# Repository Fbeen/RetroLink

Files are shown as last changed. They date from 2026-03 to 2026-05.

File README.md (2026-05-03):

# RetroLink

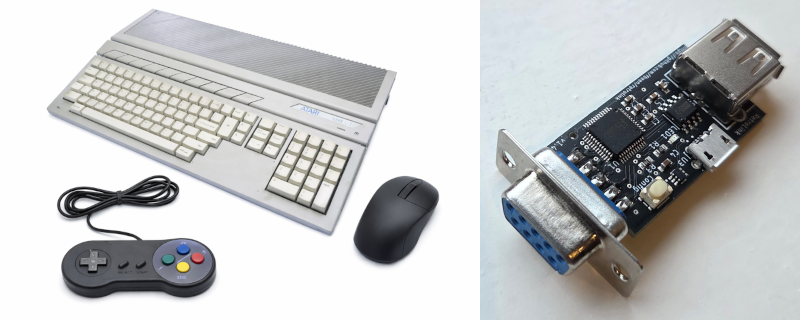
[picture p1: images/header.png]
Retro computer


RetroLink is a small **USB input adapter for retro computers**.

It allows modern **USB mice and USB joysticks** to be used on classic systems such as:

- Atari ST
- Commodore Amiga
- Commodore 64

---

## Table of Contents

- [Features](#features)
- [Button Control & LED Feedback](#button-control--led-feedback)
- [Why This Project Exists](#why-this-project-exists)
- [How RetroLink Works](#how-retrolink-works)
  - [Microcontroller](#microcontroller-ch559l)
  - [USB Host Operation](#usb-host-operation)
  - [Mouse Emulation](#mouse-emulation)
  - [Joystick Mapping](#joystick-mapping)
  - [Open Collector Outputs](#open-collector-outputs)
  - [Serial Interface](#serial-configuration-interface)
- [Hardware](#hardware)
- [Connecting RetroLink](#connecting-retrolink)
- [Configuration Console](#opening-the-configuration-console)
- [Menu Options](#main-menu)
- [Firmware](#firmware)
- [Disclaimer](#disclaimer)

---

## Features

- USB mouse support
- USB joystick support, must be a HID joystick.
- Works with **Atari 8 bit**,  **Atari ST**, **Amiga**, and **C64**
- Configurable **mouse speed**
- Switch between **ST mouse** and **Amiga mouse**
- **Swap** left & right **mouse buttons**
- Configurable **autofire frequency**
- **Joystick learning wizard**
- Configuration stored in flash memory
- Terminal-based configuration (optional)
- Configurable with onboard button & LED

---

# Button Control & LED Feedback

## Button Overview

The RetroLink uses **one button**:

- **Short press**  Show menu on UART  
- **Long press**  Select function via LED flashes  

---

## Short Press

**< 1 second**

- Prints the **Main Menu**
- Useful when opening a serial terminal  

---

## Long Press (Selection)

| Flashes | Function |
|---|---|
| 1 | Controller Learning |
| 2 | Swap Mouse Mode |
| 3 | Swap Mouse Buttons |
| 4 | Increase Mouse Speed |
| 5 | Increase Autofire Speed |

Release at desired flash count

---

## Controller Learning (1 flash)

Press a key on your controller in the order below to configure it:

1. UP  
2. DOWN  
3. LEFT  
4. RIGHT  
5. FIRE  
6. AUTOFIRE  

### Feedback

- Each step **2 short flashes**
- Final step LED ON for **2 seconds**
- Config is saved automatically

### To abort the learning wizzard:

- Press **PCB button**
- Press **ESC** in terminal

---

## Mouse Mode (2 flashes)

- 1 flash Atari ST  
- 2 flashes Amiga  

---

## Mouse Buttons (3 flashes)

- 1 flash Normal  
- 2 flashes Swapped  

---

## Mouse Speed (4 flashes)

Cycles from 1 to 5 

| Flashes | Speed |
|---|---|
| 1 | Very Slow |
| 2 | Slow |
| 3 | Normal |
| 4 | Fast |
| 5 | Turbo |

---

## Autofire Speed (5 flashes)

| Flashes | Frequency |
|---|---|
| 1 | 8 Hz |
| 2 | 9 Hz |
| 3 | 10 Hz |
| 4 | 11 Hz |
| 5 | 12 Hz |

---

## Notes

- Settings are stored in flash
- Persist after reboot
- LED is primary UI without UART

---

# Why This Project Exists

Classic hardware is aging:

- cables break  
- hardware wears out  
- ergonomics are outdated  

RetroLink solves this by allowing **modern USB devices** to be used.

---

# How RetroLink Works

RetroLink translates USB input into **DB9 signals**.

Internally:

- USB HID reports are read
- Converted to:
  - quadrature signals (mouse)
  - digital lines (joystick)
  - autofire pulses

---

## Microcontroller: CH559L

I chose the CH559 because it operates directly on the 5 volts from the retro computer and therefore does not require a power regulator. Furthermore, the CH559 microcontroller has a built-in USB transceiver and USB controller. The DB9 interfaces are electrically very simple, but they rely on a specific signaling method: open-collector (or open-drain) logic.

Key features for the CH559:

- 8051-based MCU
- USB Host + Device
- 5V operation and low current 3.3v output
- Built-in flash storage

### RAM Limitation

The disadvantage of the CH559 is the small RAM size. That's why strings are stored in flash using `__code`, for example:

    static const char __code text[] = "Example";

---

## USB Host Operation

Supports HID devices:

- mouse
- joystick
- gamepads

---

## Mouse Emulation

Uses quadrature encoding:

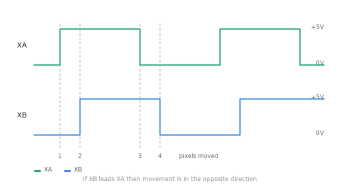
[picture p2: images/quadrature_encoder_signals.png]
quadrature


---

## Joystick Mapping

Learning wizard detects:

- changed bytes
- thresholds
- control mapping

---

## Open Collector Outputs

Uses open-drain signals:

- only pulls LOW
- host provides pull-up

---

## Serial Configuration Interface

The RX and TX UART0 lines are connected to the CH340N UART-to-USB controller. This ensures that a micro USB cable can be used for the configuration.

---

# Hardware

See the [hardware section](/hardware/readme.md).

---

# Connecting RetroLink

1. Plug into DB9 mouse or joystick port on your Atari 8 bit / ST / Amiga /C64
2. Connect HID mouse/controller to the USB-A port
3. *Optional: connect micro USB cable to your PC to use the console*
4.  For joystick emulation run the **learning wizzard** once.

---

# Opening the Configuration Console

Connect a USB cable from your pc to the micro USB port on the pcb. Any serial console could be used like:

- Arduino's serial monitor
- Visual Studio Code's serial monitor
- PuTTY
- TeraTerm
- minicom

Settings:

```
2000000 baud
8 data bits
no parity
1 stop bit
```
---

## Main Menu

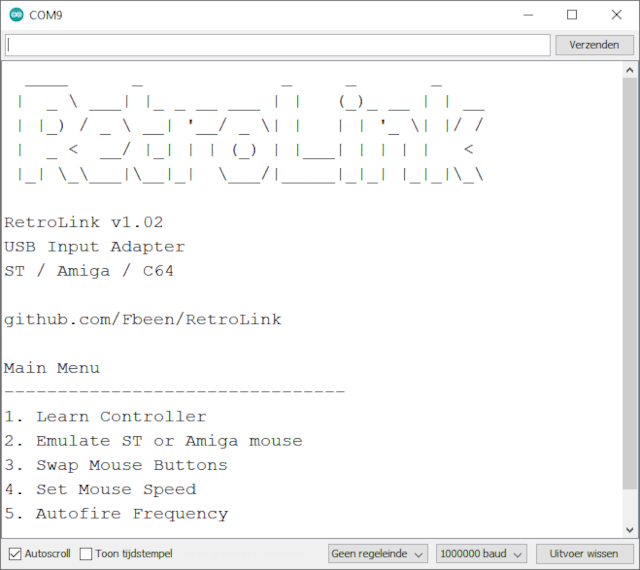
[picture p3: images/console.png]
Main menu


---

# Firmware

See the [firmware section](/firmware.md).

---

# Repository

https://github.com/Fbeen/RetroLink

---

# Disclaimer

Provided as-is. Use at your own risk.

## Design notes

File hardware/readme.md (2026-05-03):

# Hardware

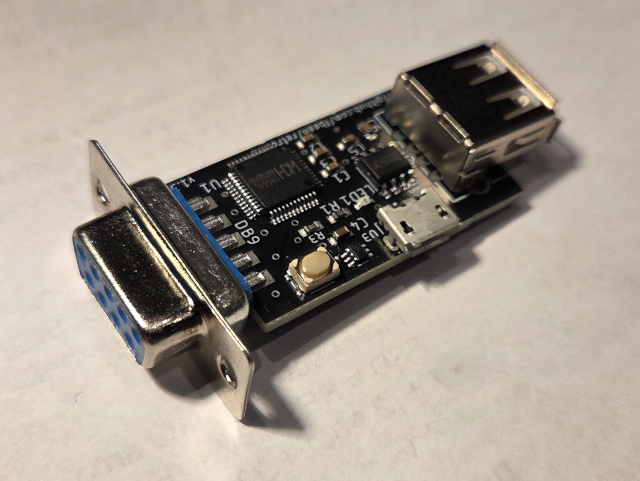
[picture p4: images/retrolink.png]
RetroLink


The RetroLink hardware was designed in **Autodesk EAGLE**.

If you want to modify the design yourself, you can download Autodesk EAGLE for free through the **Fusion 360 Personal Use License**. This license is intended for hobbyists and non-commercial projects.

Useful links:

https://www.autodesk.com/products/fusion-360/personal  
https://www.autodesk.com/products/eagle/overview  

The free version has a few limitations, but for small hobby projects like this it works perfectly fine:

- Maximum **2 schematic sheets**
- Maximum **2 signal layers**
- Maximum **100 cm² PCB area**

---

# Ordering the PCB at JLCPCB

You can simply order it **almost fully assembled** from JLCPCB.

To make this easy, the repository already contains the required manufacturing files.

You will find them here: `hardware/jlcpcb.com/`

Inside that folder you will find:

- `CAMOutput.zip` – the Gerber files (PCB manufacturing files)
- `bom.xls` – Bill of Materials
- `cpl.xls` – Component placement file

---

## Step-by-step ordering

1. Go to https://jlcpcb.com

2. Log in or create an account.

3. Press **Order Now**

4. Upload the file: `CAMOutput.zip`

5. Choose your preferred **PCB color**

6. Enable **PCB Assembly**

7. Select the quantity  
(usually **2 or 5 boards** is the cheapest option)

8. Press **Next**

9. Press **Next** again

10. Upload the assembly files

- BOM file → `bom.xls`
- CPL file → `cpl.xls`

11. Press **Process BOM & CPL**

12. **Important:** carefully check the detected parts.

13. Press **Next**

14. Check the orientation of the following components:

- **U1** → dot at **bottom-left**
- **U2** → dot at **top-right**
- **U3** → dot at **bottom-right**
- **LED** → **left = negative**, **right = positive**

15. Press **Save to cart**

16. Place your order and complete payment.

17. Now comes the hardest part: **waiting for the package to arrive.**

---

# Adding the DB9 and USB-A connectors

The **DB9** and **USB-A** connectors are **not assembled by JLCPCB**, so you will need to solder them yourself.

Luckily this is very easy and only takes a few minutes.

You will need:

- **DB9 Connector – PCB Mount – Serial – 9 Pin – 2 Rows**
- **USB-A Connector – PCB Mount**

Example connectors:

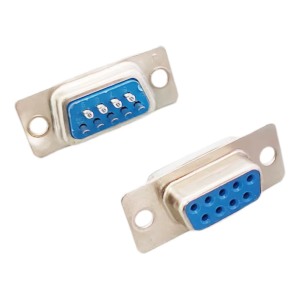
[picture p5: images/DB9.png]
DB9 Connector PCB Mount Serial 9 Pin 2 Rows


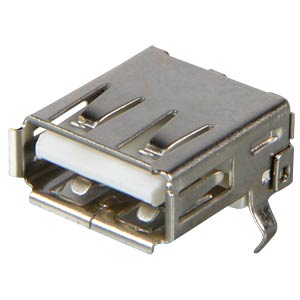
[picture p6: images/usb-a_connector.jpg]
USB-A connector pcb mount


---

# Compiling and flashing the firmware (Windows)

The **CH559L microcontroller** can be programmed directly through USB.

For this you will need a **USB-A to USB-A cable**.

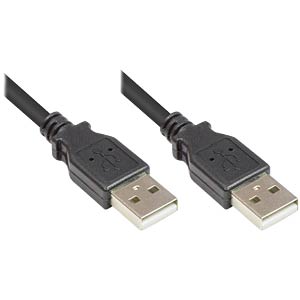
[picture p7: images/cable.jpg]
USB-A to USB-A cable


---

## Compiling and flashing instructions

1. Clone the complete repository

https://github.com/Fbeen/RetroLink

or use:

```
git clone https://github.com/Fbeen/RetroLink
```

2. Open a **Command Prompt** in Windows.

3. Change to the repository directory

```
cd RetroLink
```

4. Connect the PCB to your computer using the **USB-A to USB-A cable**  
while **holding the button on the PCB**.

5. If everything goes well you should hear the familiar  
**"new USB device detected"** sound from Windows.

6. Run the build script:

```
cd scripts
compile
```

The firmware will now be compiled and flashed to the **CH559L**.

---

# Repository

The complete project can be found here:

https://github.com/Fbeen/RetroLink

Feel free to explore the project, modify the hardware or firmware, and build your own RetroLink adapter.

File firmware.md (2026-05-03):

# RetroLink Firmware (CH559)

Firmware for the RetroLink adapter: a USB-to-retro controller interface (Atari ST / Amiga / C64).

This firmware runs on the **CH559 (8051 + USB host)** and translates USB HID input (mouse / joystick / gamepad) into classic digital and quadrature signals.

---

## Compiling and flashing instructions

See the [hardware section](/hardware/readme.md#compiling-and-flashing-the-firmware-windows).

---

## About the Firmware Language

This firmware is written in a specialized dialect of **C targeting the 8051 architecture**, specifically for the **WCH CH559 microcontroller**.

Although it looks like standard C, there are several important differences compared to desktop or ARM-based embedded development:

- Uses **8051-specific memory qualifiers** such as:
  - `__code` (flash memory)
  - `__xdata`, `__idata`, etc. (different RAM regions)
- Strong awareness of **very limited RAM**
- Heavy reliance on **interrupt-driven design**
- Direct manipulation of **special function registers (SFRs)**
- Tight coupling to hardware timing (especially for quadrature signals)

Because of this, the code is closer to **"embedded C for 8-bit MCUs"** than modern C used on platforms like ARM Cortex (e.g. STM32 or RP2040).

### Why this matters

If you plan to modify or extend this firmware:

- Be mindful of **memory placement** (RAM vs flash)
- Avoid large stack usage or dynamic allocation
- Keep interrupt routines **fast and deterministic**
- Understand that some constructs are compiler- or architecture-specific

In short: this is **low-level, hardware-near C**, optimized for a small 8-bit microcontroller rather than a general-purpose system.

---

# Purpose of this README

This document is intended to:

- Help new developers quickly understand the project
- Make maintenance and extensions easier
- Provide insight into architecture, timing, and hardware interaction

---

# Project Structure

The firmware is modular and split by functionality:

    main.c              entry point + main loop + timers
    USBHost.c           USB host stack + HID handling
    hid_mouse.c         USB mouse report parsing
    hid_joystick.c      USB joystick/gamepad parsing

    retro_mouse.c       quadrature signal generation (Atari/Amiga)
    retro_joystick.c    digital joystick output

    hardware.c          GPIO setup and hardware initialization
    led.c               LED timing and animations
    console.c           UART debug / configuration interface

    config.c            persistent configuration + mappings
    util.c              helper functions

---

# Firmware Architecture

## 1. Data Flow (High-Level)

### Mouse pipeline:

    USB HID report
     hid_mouse_parse()
     movement buffer (mx/my)
     timer interrupt
     rm_nextStep()
     quadrature output (PORT2)

### Joystick pipeline:

    USB HID report
     hid_joystick_parse()
     mapping via config
     direct GPIO output (ACTIVE LOW)

---

## 2. Main Loop (main.c)

`main.c` is responsible for:

- Initialization:
  - Clock setup
  - USB host
  - GPIO
  - Timers
- Polling:
  - USB devices (USBHost_*)
- Mode switching:
  - Mouse vs joystick

---

# GPIO & Hardware

## GPIO Definition

GPIO is centrally managed in:

    hardware.c

This file defines:

- Direction (input/output)
- Open-drain / push-pull modes
- Default signal levels

### Important:

- **All joystick signals are ACTIVE LOW**
- Idle = HIGH
- Active = LOW

---

## Output Mapping

Typically using `PORT2`:

| Function | Signal |
|---|---|
| UP | GPIO |
| DOWN | GPIO |
| LEFT | GPIO |
| RIGHT | GPIO |
| FIRE | GPIO |

Mouse signals:

- Quadrature signals (X1/X2, Y1/Y2)
- Layout differs between Atari ST and Amiga

---

## Open Drain Behavior

The firmware uses:

- Open-drain / open-collector style outputs
- Safe for retro hardware
- Mimics original joystick electronics

---

# Timers

## Timer0 (Main Timing Engine)

Used for:

- Mouse quadrature timing
- Autofire
- LED timing
- Button handling

Configured in `main.c`:

    #define mTimer0ClkFsys()

---

## Timing Functions

### 1. Mouse Stepping

Executed in ISR:

    rm_nextStep()

- Processes mx/my buffers
- Generates correct quadrature phase sequence

---

### 2. Autofire

Key variables:

    autofire_counter
    autofire_state

- ~2400 Hz interrupt base
- ~10 Hz output signal

---

### 3. Button Timing

    BTN_STEP   = 10   ~1 second
    BTN_T_BOOT = 100  ~10 seconds

Used for:

- Short press detection
- Long press detection
- Menu selection

---

# USB HID Processing

## USB Stack

File:

    USBHost.c

Responsibilities:

- Device enumeration
- HID interface selection
- Polling

---

## Device Detection

- Protocol 2 Mouse
- Otherwise Joystick/Gamepad

---

## Parsing

### Mouse:

    hid_mouse.c

- X/Y movement
- Buttons

### Joystick:

    hid_joystick.c

- Axis direction
- Buttons fire/autofire

---

# Retro Output

## Mouse (retro_mouse.c)

- Maintains mx/my buffers
- Generates quadrature signals
- Supports:
  - Atari ST
  - Amiga

---

## Joystick (retro_joystick.c)

- Direct GPIO mapping
- Active LOW output
- Configurable mapping

---

# Configuration

File:

    config.c

Contains:

- Controller mappings
- Mouse speed
- Autofire settings
- Button swap
- Mode (ST/Amiga)

Storage:

- Flash memory
- Version/magic validation

---

# LED & UI

File:

    led.c

Handles:

- Status feedback
- Menu navigation

---

## Button + LED UI

| Action | Result |
|---|---|
| Short press  | Show menu (UART)  |
| Long press | Select option |
| LED flashes  | Menu index |

---

# Console (UART)

File:

    console.c

Features:

- Debug output
- Configuration interface
- Menu system

---

# Utilities

File:

    util.c

Contains:

- Helper functions
- Parsing utilities
- General shared logic

---

# Important Notes

## 1. Limited RAM

- CH559 has very limited RAM
- Store constant data in `__code` (flash)

---

## 2. Timing is Critical

- Mouse quadrature must be precise
- ISR must remain lightweight

---

## 3. USB Polling

- Must run frequently
- Avoid blocking code in main loop

---

## 4. Open Drain Outputs

- Never force push-pull on retro lines
- Prevents hardware damage

---

# How to Extend

## Adding New Features

Typical workflow:

1. Extend parsing in:
   - hid_*
2. Add mapping in:
   - config.c
3. Adjust output in:
   - retro_*
4. Extend UI:
   - console.c
   - led.c

---

## Adding New Hardware

- Update GPIO config in `hardware.c`
- Keep mappings consistent

---

# Summary

This firmware is built around:

- **USB HID input**
- **Timer-driven output**
- **Strict timing**
- **Modular design**

Core principles:

- Keep ISR minimal
- Use buffers for decoupling
- Drive hardware safely

---

# Final Notes

If you want to understand or extend this project:

1. Start with `main.c` (overall flow)
2. Then study `USBHost.c` (input layer)
3. Finally inspect `retro_*` (output layer)

This gives you a complete understanding of the system.

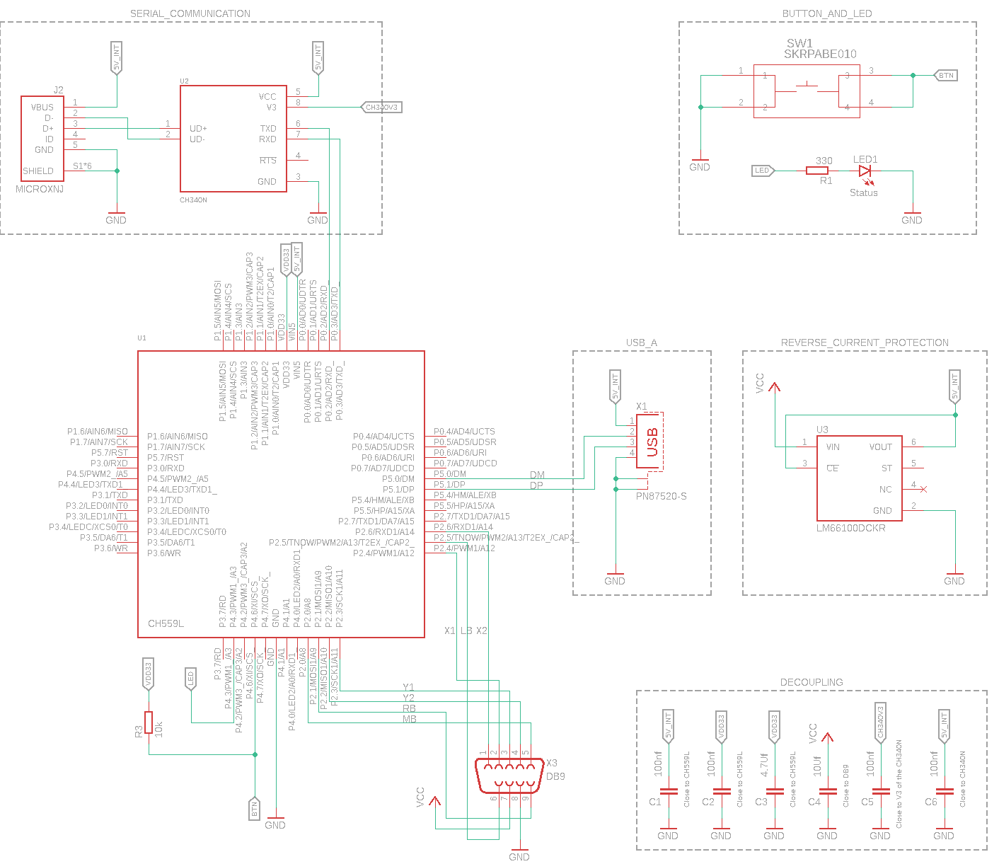
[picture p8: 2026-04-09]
hardware/schema.png

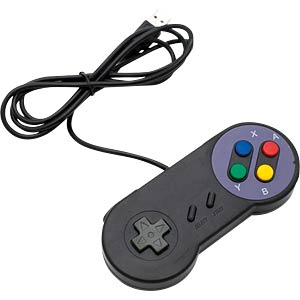
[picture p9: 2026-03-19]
images/gamepad.jpg

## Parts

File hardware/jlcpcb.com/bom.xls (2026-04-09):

Comment | Designator | Footprint | JLCPCB Part #
100nf | C1 | C0603 | C14663
100nf | C2 | C0603 | C14663
4.7Uf | C3 | C0603 | C107368
10Uf | C4 | C0603 | C49326609
100nf | C5 | C0603 | C14663
100nf | C6 | C0603 | C14663
USB-MICRO XNJ JB | J1 | Custom | C7507410
Status | LED1 | SML0603 | C2287
330 | R1 | R0603 | C23138
10k | R3 | R0603 | C25804
SKRPABE010 | SW1 | SW4_SKRPABE010_ALPS | C115360
CH559L | U1 | TQFP48_7X7 | C150548
CH340N | U2 | SOIC127P600X160-8N | C2977777
LM66100DCKR | U3 | SOT65P210X110-6N | C2869734

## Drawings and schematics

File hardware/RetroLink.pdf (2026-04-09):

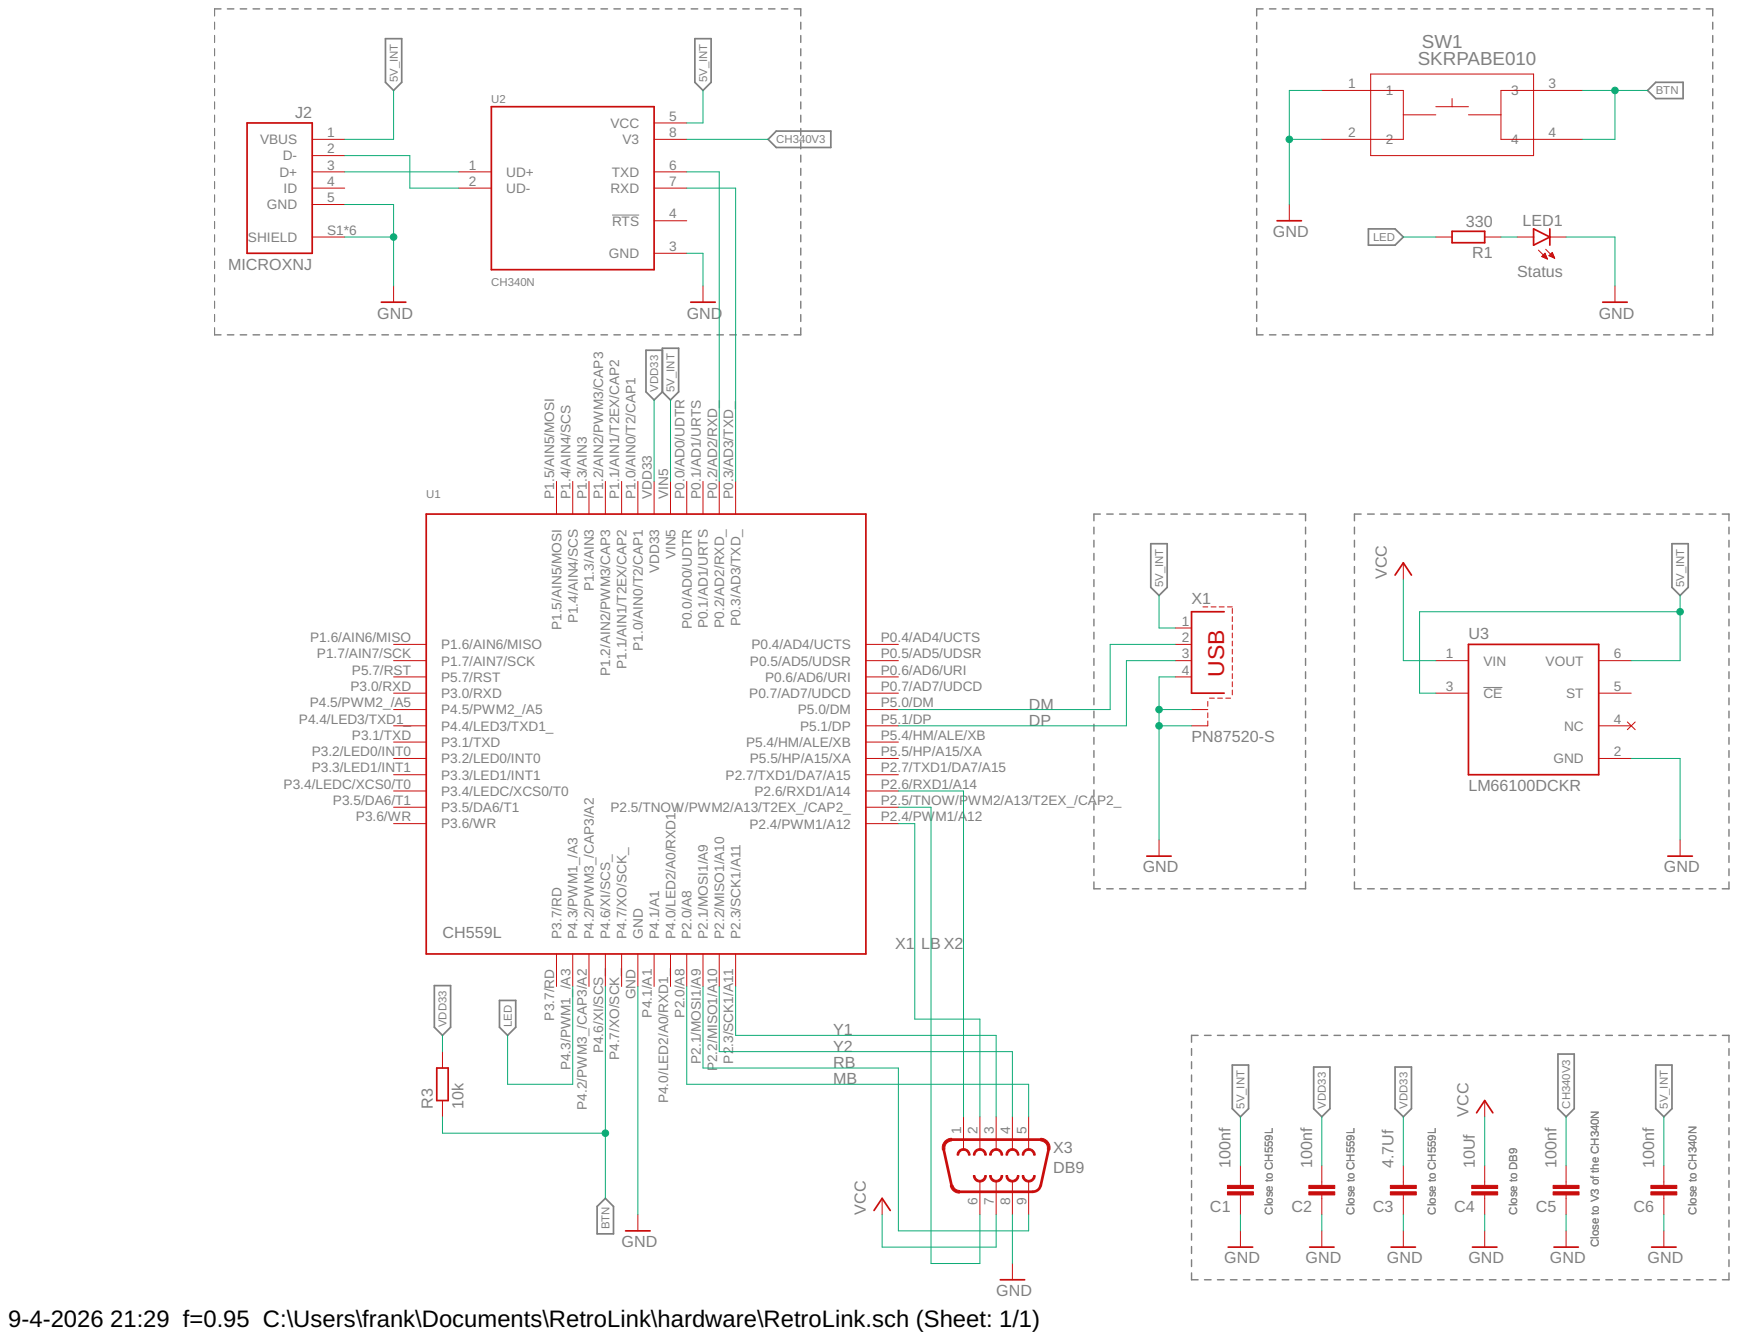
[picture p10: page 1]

3 GND | 6 RXD

P4.1/A1 P4.1/A1 P4.0/LED2/A0/RXD1_ P4.0/LED2/A0/RXD1_ P2.0/A8 P2.0/A8 P2.1/MOSI1/A9 P2.1/MOSI1/A9 P2.2/MISO1/A10 P2.2/MISO1/A10 P2.3/SCK1/A11 P2.3/SCK1/A11 P2.4/PWM1/A12 P2.4/PWM1/A12 P2.5/TNOW/PWM2/A13/T2EX_/CAP2_ P2.5/TNOW/PWM2/A13/T2EX_/CAP2_ P2.6/RXD1/A14 P2.6/RXD1/A14 P2.7/TXD1/DA7/A15 P2.7/TXD1/DA7/A15 P5.5/HP/A15/XA

P4.3/PWM1_/A3 P4.3/PWM1_/A3 P4.2/PWM3_/CAP3/A2 P4.2/PWM3_/CAP3/A2 P4.6/XI/SCS_ P4.6/XI/SCS_ P4.7/XO/SCK_ P4.7/XO/SCK_ GND GND

Close to V3 of the CH340N

9-4-2026 21:29 f=0.95 C:\Users\frank\Documents\RetroLink\hardware\RetroLink.sch (Sheet: 1/1)

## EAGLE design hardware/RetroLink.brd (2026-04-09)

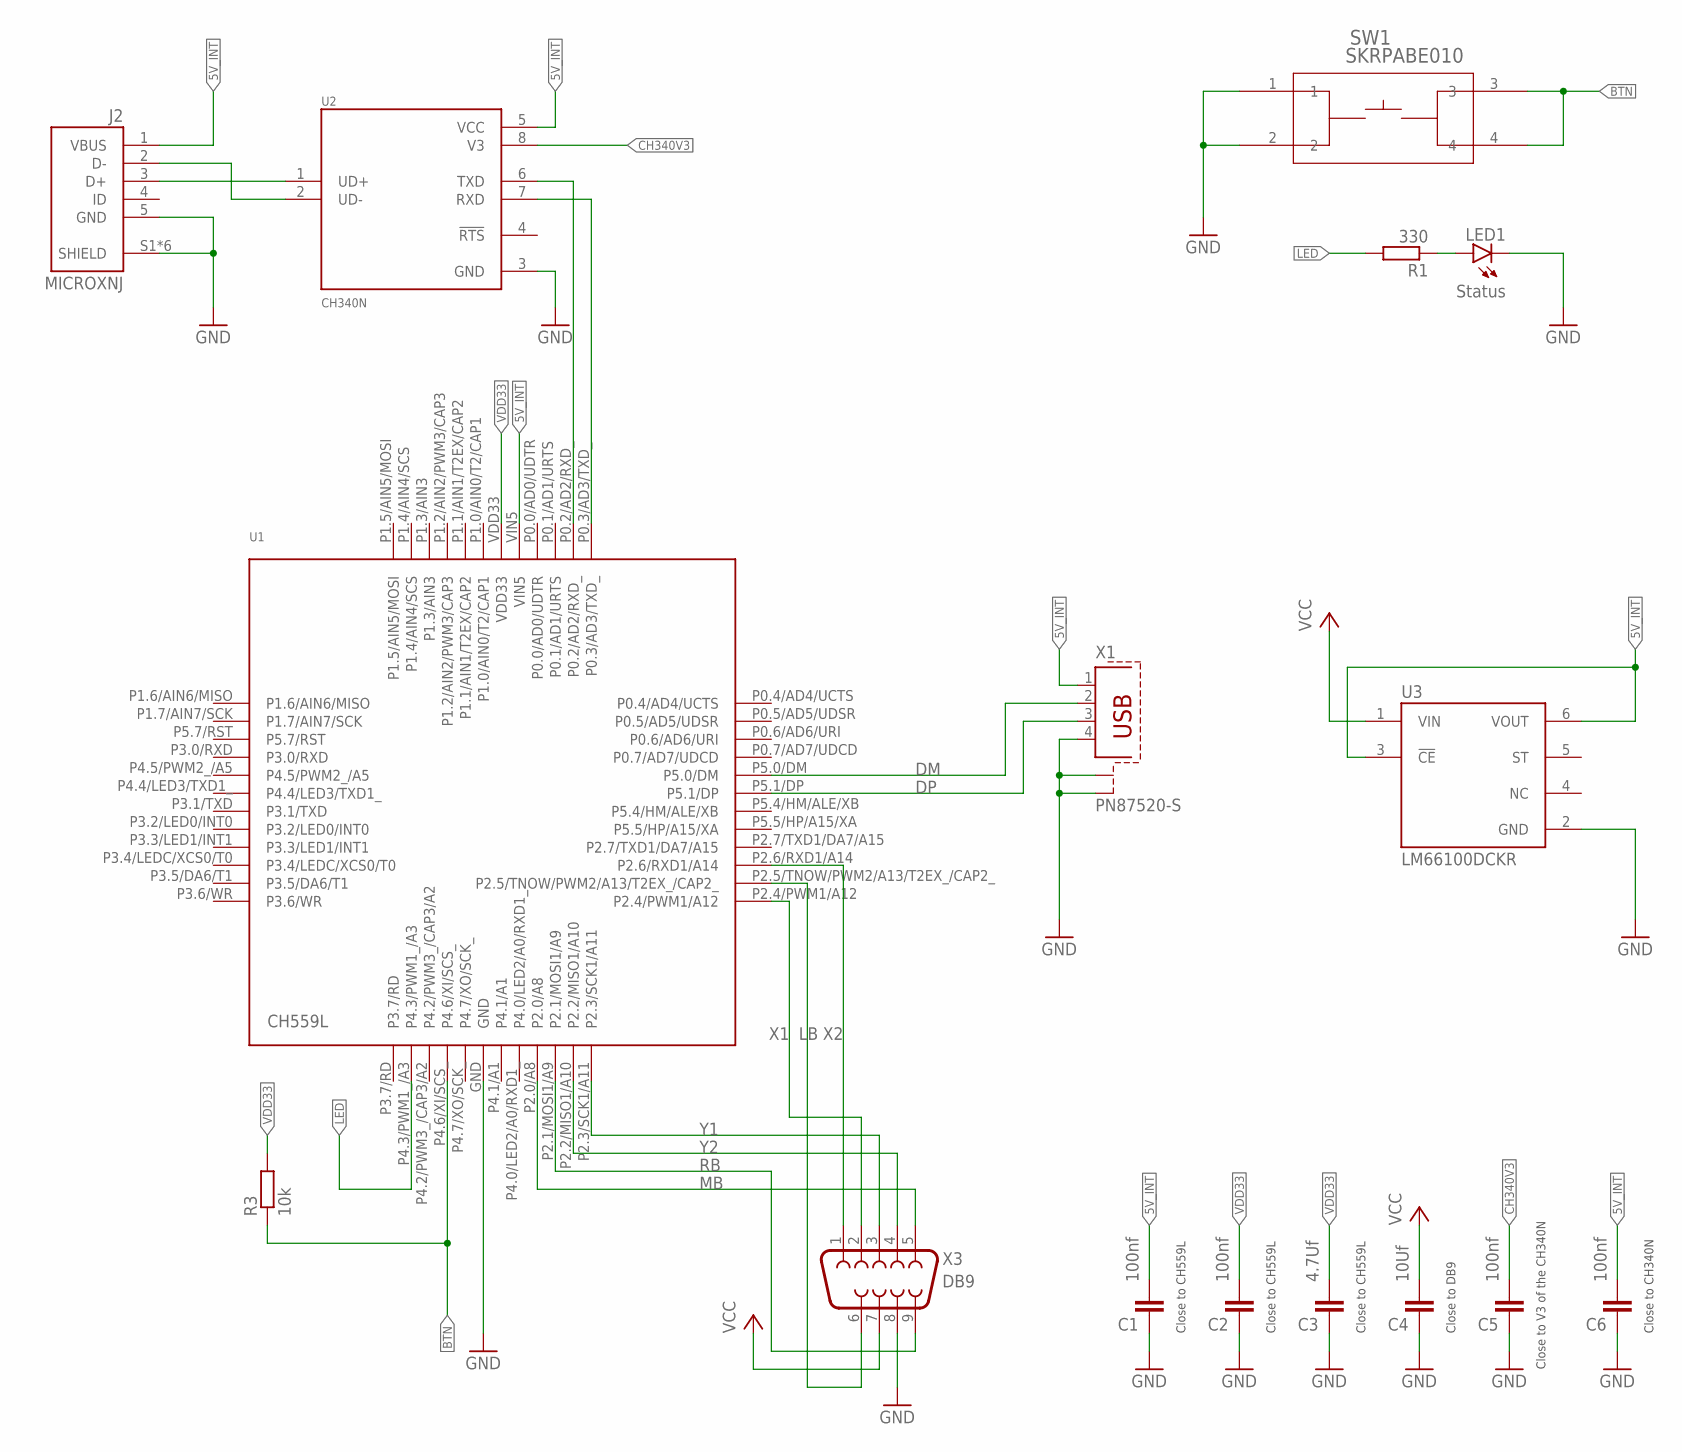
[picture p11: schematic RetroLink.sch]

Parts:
C1, C2, C5, C6: 100nf; C0603
C3: 4.7Uf; C0603
C4: 10Uf; C0603
J2: MICROXNJ; SHOUHAN_MICROXNJ
LED1: Status; SML0603
R1: 330; R0603
R3: 10k; R0603
SW1: SKRPABE010; SW4_SKRPABE010_ALPS
U1: CH559L; TQFP48_7X7
U2: CH340N; SOIC127P600X160-8N
U3: LM66100DCKR; SOT65P210X110-6N
X1: PN87520-S
X3: DB9; F09D

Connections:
5V_INT: C1.2, C6.2, J2.1 (VBUS), U1.VIN5, U2.5 (VCC), U3.3 (!CE), U3.6 (VOUT), X1.1
BTN: R3.1, SW1.3, SW1.4, U1.P4.6/XI/SCS_
CH340V3: C5.2, U2.8 (V3)
DM: U1.P5.0/DM, X1.2
DP: U1.P5.1/DP, X1.3
GND: C1.1, C2.1, C3.1, C4.1, C5.1, C6.1, J2.5 (GND), J2.S1 (SHIELD), J2.S2 (SHIELD), J2.S3 (SHIELD), J2.S4 (SHIELD), J2.S5 (SHIELD), J2.S6 (SHIELD), LED1.C, SW1.1, SW1.2, U1.GND, U2.3 (GND), U3.2 (GND), X1.4, X1.S1, X1.S2, X3.8
LB: U1.P2.5/TNOW/PWM2/A13/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, X3.6
LED: R1.2, U1.P4.3/PWM1_/A3
MB: U1.P2.0/A8, X3.5
unnamed: J2.2 (D-), U2.2 (UD-)
unnamed: J2.3 (D+), U2.1 (UD+)
RB: U1.P2.1/MOSI1/A9, X3.9
RXD: U1.P0.2/AD2/RXD_, U2.6 (TXD)
TXD: U1.P0.3/AD3/TXD_, U2.7 (RXD)
VCC: C4.2, U3.1 (VIN), X3.7
VDD33: C2.2, C3.2, R3.2, U1.VDD33
VLED: LED1.A, R1.1
X1: U1.P2.4/PWM1/A12, X3.2
X2: U1.P2.6/RXD1/A14, X3.1
Y1: U1.P2.3/SCK1/A11, X3.3
Y2: U1.P2.2/MISO1/A10, X3.4

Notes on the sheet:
Close to DB9
Close to CH559L
Close to CH340N
Close to V3 of the CH340N

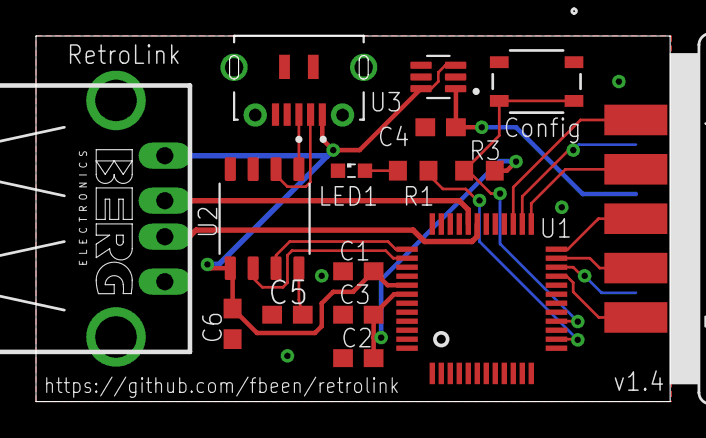
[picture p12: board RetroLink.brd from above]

Board: 2 copper layers, 35.2 x 20.3 mm, 16 parts (0 on the bottom side), 21 nets.

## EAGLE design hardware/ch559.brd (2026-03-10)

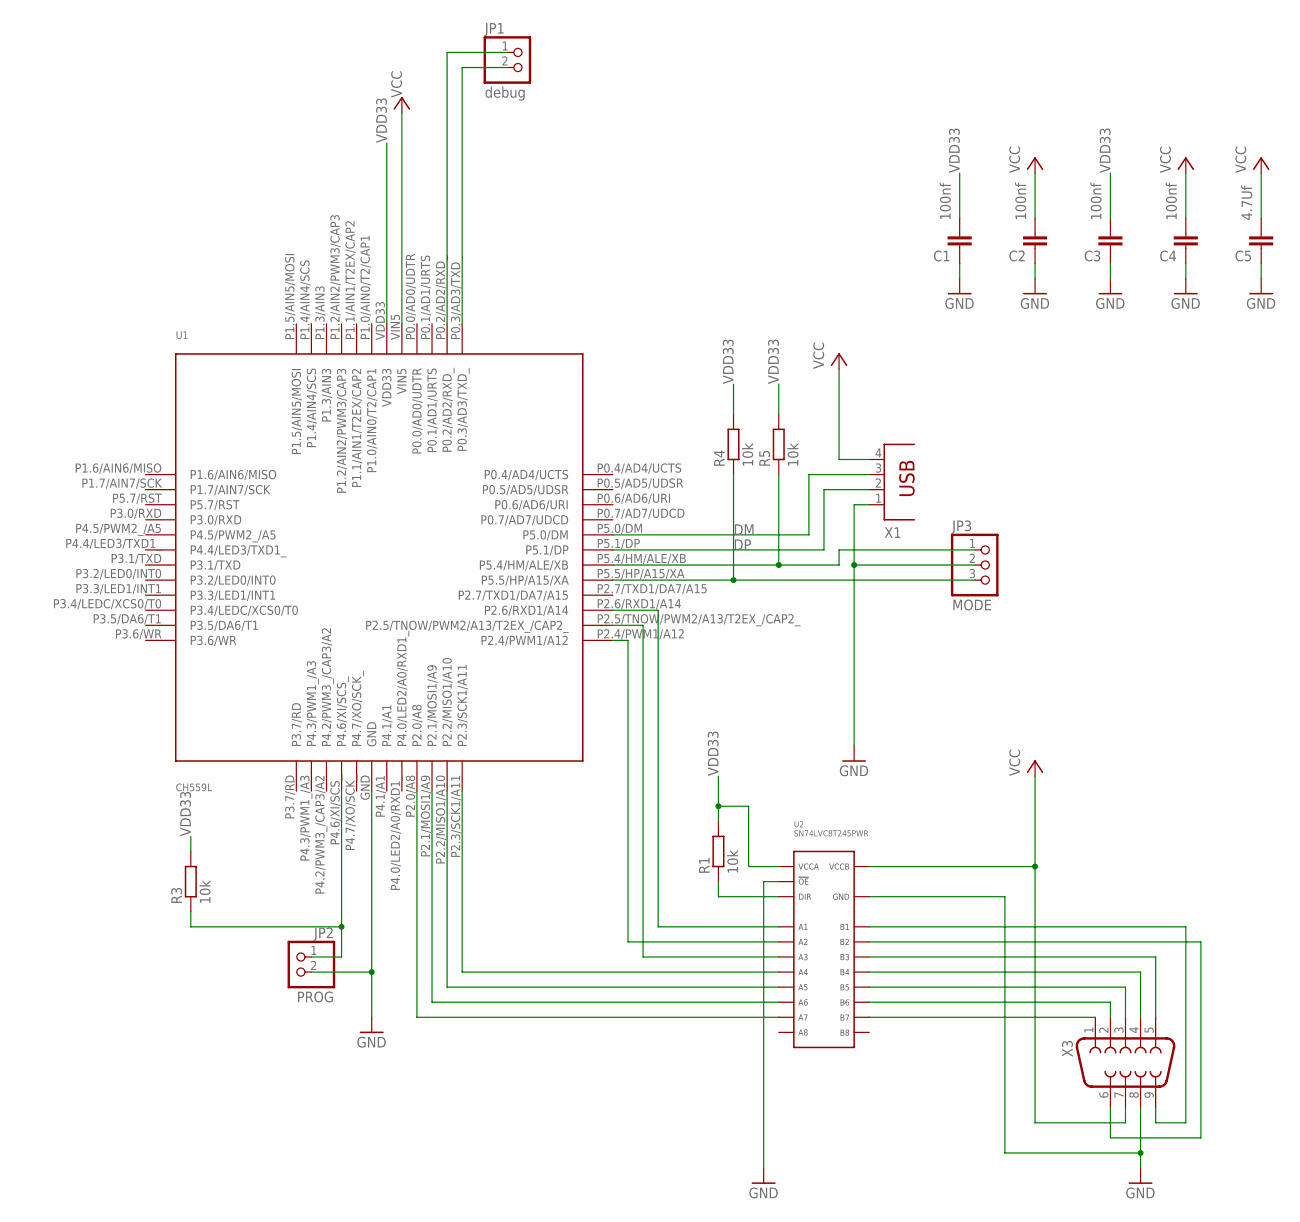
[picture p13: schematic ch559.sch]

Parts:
C1, C2, C3, C4: 100nf; C0603
C5: 4.7Uf; C0603
JP1: debug; 1X02
JP2: PROG; 1X02
JP3: MODE; 1X03
R1, R3, R4, R5: 10k; R0603
U1: CH559L; TQFP48_7X7
U2: SN74LVC8T245PWR; TTSOP-24
X1: PN87520
X3: F09D

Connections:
DM: U1.P5.0/DM, X1.3
DP: U1.P5.1/DP, X1.2
GND: C1.1, C2.1, C3.1, C4.1, C5.1, JP2.2, JP3.2, U1.GND, U2.P$11 (GND), U2.P$12 (GND), U2.P$13 (GND), U2.P$22 (!OE), X1.1, X3.8
LB: U2.P$17 (B5), X3.3
unnamed: U2.P$15 (B7), X3.1
unnamed: U2.P$20 (B2), X3.6
unnamed: U2.P$21 (B1), X3.9
unnamed: JP3.1, R5.1, U1.P5.4/HM/ALE/XB
unnamed: JP3.3, R4.1, U1.P5.5/HP/A15/XA
unnamed: R1.1, U2.P$2 (DIR)
P2.0: U1.P2.0/A8, U2.P$9 (A7)
P2.1: U1.P2.1/MOSI1/A9, U2.P$8 (A6)
P2.2: U1.P2.2/MISO1/A10, U2.P$7 (A5)
P2.3: U1.P2.3/SCK1/A11, U2.P$6 (A4)
P2.4: U1.P2.4/PWM1/A12, U2.P$4 (A2)
P2.5: U1.P2.5/TNOW/PWM2/A13/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, U2.P$5 (A3)
P2.6: U1.P2.6/RXD1/A14, U2.P$3 (A1)
PROG: JP2.1, R3.1, U1.P4.6/XI/SCS_
RB: U2.P$16 (B6), X3.2
RXD: JP1.1, U1.P0.2/AD2/RXD_
TXD: JP1.2, U1.P0.3/AD3/TXD_
VCC: C2.2, C4.2, C5.2, U1.VIN5, U2.P$23 (VCCB), U2.P$24 (VCCB), X1.4, X3.7
VDD33: C1.2, C3.2, R1.2, R3.2, R4.2, R5.2, U1.VDD33, U2.P$1 (VCCA)
Y1: U2.P$19 (B3), X3.5
Y2: U2.P$18 (B4), X3.4

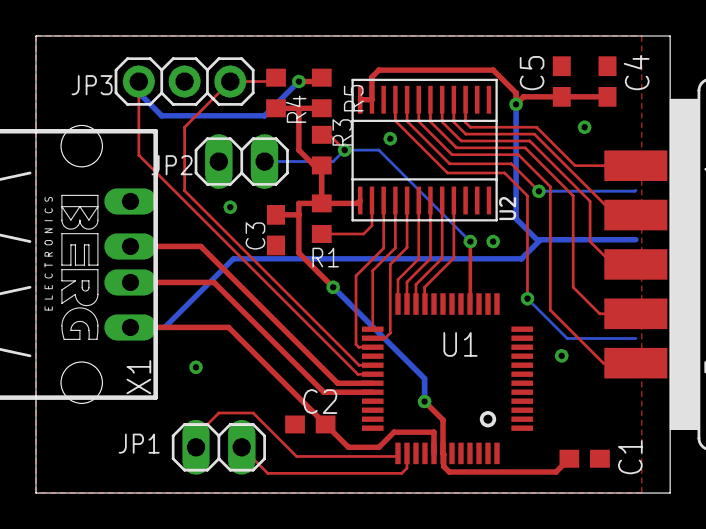
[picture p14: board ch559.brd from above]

Board: 2 copper layers, 35.2 x 25.4 mm, 16 parts (0 on the bottom side), 25 nets.

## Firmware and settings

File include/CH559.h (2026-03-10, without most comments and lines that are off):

#define __CH559_H__
typedef unsigned char volatile __xdata    UINT8XV;
typedef unsigned char volatile __pdata    UINT8PV;
#include <compiler.h>
#include <stdint.h>
SFR(PSW,	0xD0);	// program status word
   SBIT(CY,	0xD0, 7);	// carry flag
   SBIT(AC,	0xD0, 6);	// auxiliary carry flag
   SBIT(F0,	0xD0, 5);	// bit addressable general purpose flag 0
   SBIT(RS1,	0xD0, 4);	// register R0-R7 bank selection high bit
   SBIT(RS0,	0xD0, 3);	// register R0-R7 bank selection low bit
#define MASK_PSW_RS       0x18      // bit mask of register R0-R7 bank selection
   SBIT(OV,	0xD0, 2);	// overflow flag
   SBIT(F1,	0xD0, 1);	// bit addressable general purpose flag 1
   SBIT(P,	0xD0, 0);	// ReadOnly: parity flag
SFR(ACC,	0xE0);	// accumulator
SFR(B,	0xF0);	// general purpose register B
SFR(SP,	0x81);	// stack pointer
SFR(DPL,	0x82);	// data pointer low
SFR(DPH,	0x83);	// data pointer high
SFR(SAFE_MOD,	0xA1);	// WriteOnly: writing safe mode
#define CHIP_ID           SAFE_MOD
SFR(GLOBAL_CFG,	0xB1);	// global config, Write@SafeMode
#define bBOOT_LOAD        0x20      // ReadOnly: boot loader status for discriminating BootLoader or Application: set 1 by power on reset, clear 0 by software reset
#define bSW_RESET         0x10      // software reset bit, auto clear by hardware
#define bCODE_WE          0x08      // enable flash-ROM (include code & data area) being program or erasing: 0=writing protect, 1=enable program and erase
#define bDATA_WE          0x04      // enable Data-Flash (flash-ROM data area) being program or erasing: 0=writing protect, 1=enable program and erase
#define bXIR_XSFR         0x02      // force MOVX_@R0/@R1 only for xSFR area: 0=MOVX_@R0/@R1 for standard xdata area inclde xRAM&xBUS&xSFR, 1=MOVX_@R0/@R1 for xSFR only
#define bWDOG_EN          0x01      // enable watch-dog reset if watch-dog timer overflow: 0=as timer only, 1=enable reset if timer overflow
SFR(PCON,	0x87);	// power control and reset flag
#define SMOD              0x80      // baud rate selection for UART0 mode 1/2/3: 0=slow(Fsys/128 @mode2, TF1/32 @mode1/3, no effect for TF2),
#define bRST_FLAG1        0x20      // ReadOnly: recent reset flag high bit
#define bRST_FLAG0        0x10      // ReadOnly: recent reset flag low bit
#define MASK_RST_FLAG     0x30      // ReadOnly: bit mask of recent reset flag
#define RST_FLAG_SW       0x00
#define RST_FLAG_POR      0x10
#define RST_FLAG_WDOG     0x20
#define RST_FLAG_PIN      0x30
#define GF1               0x08      // general purpose flag bit 1
#define GF0               0x04      // general purpose flag bit 0
#define PD                0x02      // power-down enable bit, auto clear by wake-up hardware
SFR(PLL_CFG,	0xB2);	// PLL clock config: lower 5 bits for PLL clock Fpll, upper 3 bits for USB 4x clock Fusb4x, Write@SafeMode
#define MASK_PLL_MULT     0x1F      // bit mask of PLL clock Fpll multiple
#define MASK_USB_4X_DIV   0xE0      // bit mask of USB 4x clock Fusb4x divisor, value 000b means 1000b
SFR(CLOCK_CFG,	0xB3);	// system clock config: lower 5 bits for system clock Fsys, Write@SafeMode
#define bOSC_EN_INT       0x80      // internal oscillator enable and original clock selection: 1=enable & select internal clock, 0=disable & select external clock
#define bOSC_EN_XT        0x40      // external oscillator enable, need quartz crystal or ceramic resonator between X1 and X2 pins
#define bWDOG_IF_TO       0x20      // ReadOnly: watch-dog timer overflow interrupt flag, cleared by reload watch-dog count or auto cleared when MCU enter interrupt routine
#define MASK_SYS_CK_DIV   0x1F      // bit mask of system clock Fsys divisor, value 00000b means 100000b
SFR(SLEEP_CTRL,	0xEA);	// sleep control, Write@SafeMode
#define bSLP_OFF_USB      0x80      // clock off for USB
#define bSLP_OFF_ADC      0x40      // clock off for ADC
#define bSLP_OFF_UART1    0x20      // clock off for UART1
#define bSLP_OFF_P1S1     0x10      // clock off for PWM1 / SPI1
#define bSLP_OFF_SPI0     0x08      // clock off for SPI0
#define bSLP_OFF_TMR3     0x04      // clock off for timer3
#define bSLP_OFF_LED      0x02      // clock off for LED
#define bSLP_OFF_XRAM     0x01      // clock off for xRAM
SFR(WAKE_CTRL,	0xEB);	// wake-up control, Write@SafeMode
#define bWAK_BY_USB       0x80      // enable wake-up by USB event
#define bWAK_RXD1_LO      0x40      // enable wake-up by RXD1 low level
#define bWAK_P1_5_LO      0x20      // enable wake-up by pin P1.5 low level
#define bWAK_P1_4_LO      0x10      // enable wake-up by pin P1.4 low level
#define bWAK_P0_3_LO      0x08      // enable wake-up by pin P0.3 low level
#define bWAK_CAP3_LO      0x04      // enable wake-up by CAP3 low level
#define bWAK_P3_2E_3L     0x02      // enable wake-up by pin P3.2 (INT0) edge or pin P3.3 (INT1) low level
#define bWAK_RXD0_LO      0x01      // enable wake-up by RXD0 low level
SFR(RESET_KEEP,	0xFE);	// value keeper during reset
SFR(WDOG_COUNT,	0xFF);	// watch-dog count, count by clock frequency Fsys/262144
SFR(IE,	0xA8);	// interrupt enable
   SBIT(EA,	0xA8, 7);	// enable global interrupts: 0=disable, 1=enable if E_DIS=0
   SBIT(E_DIS,	0xA8, 6);	// disable global interrupts, intend to inhibit interrupt during some flash-ROM operation: 0=enable if EA=1, 1=disable
   SBIT(ET2,	0xA8, 5);	// enable timer2 interrupt
   SBIT(ES,	0xA8, 4);	// enable UART0 interrupt
   SBIT(ET1,	0xA8, 3);	// enable timer1 interrupt
   SBIT(EX1,	0xA8, 2);	// enable external interrupt INT1
   SBIT(ET0,	0xA8, 1);	// enable timer0 interrupt
   SBIT(EX0,	0xA8, 0);	// enable external interrupt INT0 or LED interrupt
SFR(IP,	0xB8);	// interrupt priority and current priority
   SBIT(PH_FLAG,	0xB8, 7);	// ReadOnly: high level priority action flag
   SBIT(PL_FLAG,	0xB8, 6);	// ReadOnly: low level priority action flag
   SBIT(PT2,	0xB8, 5);	// timer2 interrupt priority level
   SBIT(PS,	0xB8, 4);	// UART0 interrupt priority level
   SBIT(PT1,	0xB8, 3);	// timer1 interrupt priority level
   SBIT(PX1,	0xB8, 2);	// external interrupt INT1 priority level
   SBIT(PT0,	0xB8, 1);	// timer0 interrupt priority level
   SBIT(PX0,	0xB8, 0);	// external interrupt INT0 priority level
SFR(IE_EX,	0xE8);	// extend interrupt enable
   SBIT(IE_WDOG,	0xE8, 7);	// enable watch-dog timer interrupt
   SBIT(IE_GPIO,	0xE8, 6);	// enable GPIO input interrupt
   SBIT(IE_PWM1,	0xE8, 5);	// enable PWM1 interrupt
   SBIT(IE_UART1,	0xE8, 4);	// enable UART1 interrupt
   SBIT(IE_ADC,	0xE8, 3);	// enable ADC interrupt
   SBIT(IE_USB,	0xE8, 2);	// enable USB interrupt
   SBIT(IE_TMR3,	0xE8, 1);	// enable timer3 interrupt
   SBIT(IE_SPI0,	0xE8, 0);	// enable SPI0 interrupt
SFR(IP_EX,	0xE9);	// extend interrupt priority
#define bIP_LEVEL         0x80      // ReadOnly: current interrupt nested level: 0=no interrupt or two levels, 1=one level
#define bIP_GPIO          0x40      // GPIO input interrupt priority level
#define bIP_PWM1          0x20      // PWM1 interrupt priority level
#define bIP_UART1         0x10      // UART1 interrupt priority level
#define bIP_ADC           0x08      // ADC interrupt priority level
#define bIP_USB           0x04      // USB interrupt priority level
#define bIP_TMR3          0x02      // timer3 interrupt priority level
#define bIP_SPI0          0x01      // SPI0 interrupt priority level
SFR(GPIO_IE,	0xCF);	// GPIO interrupt enable
#define bIE_IO_EDGE       0x80      // enable GPIO edge interrupt: 0=low/high level, 1=falling/rising edge
#define bIE_RXD1_LO       0x40      // enable interrupt by RXD1 low level / falling edge
#define bIE_P5_5_HI       0x20      // enable interrupt by pin P5.5 high level / rising edge
#define bIE_P1_4_LO       0x10      // enable interrupt by pin P1.4 low level / falling edge
#define bIE_P0_3_LO       0x08      // enable interrupt by pin P0.3 low level / falling edge
#define bIE_P5_7_HI       0x04      // enable interrupt by pin P5.7 (RST) high level / rising edge
#define bIE_P4_1_LO       0x02      // enable interrupt by pin P4.1 low level / falling edge
#define bIE_RXD0_LO       0x01      // enable interrupt by RXD0 low level / falling edge
SFR16(ROM_ADDR,	0x84);	// address for flash-ROM, little-endian
SFR(ROM_ADDR_L,	0x84);	// address low byte for flash-ROM
SFR(ROM_ADDR_H,	0x85);	// address high byte for flash-ROM
SFR16(ROM_DATA,	0x8E);	// data for flash-ROM writing, little-endian
SFR(ROM_DATA_L,	0x8E);	// data low byte for flash-ROM writing
SFR(ROM_DATA_H,	0x8F);	// data high byte for flash-ROM writing
SFR(ROM_CTRL,	0x86);	// WriteOnly: flash-ROM control
#define ROM_CMD_PROG      0x9A      // WriteOnly: flash-ROM word program operation command, for changing some ROM bit of a word from 1 to 0
#define ROM_CMD_ERASE     0xA6      // WriteOnly: flash-ROM sector erase operation command, for changing all ROM bit of 1KBytes from 0 to 1
#define ROM_STATUS        ROM_CTRL
#define bROM_ADDR_OK      0x40      // ReadOnly: flash-ROM operation address valid flag, can be reviewed before or after operation: 0=invalid parameter, 1=address valid
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

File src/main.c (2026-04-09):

typedef unsigned char *PUINT8;
typedef unsigned char __xdata *PUINT8X;
typedef const unsigned char __code *PUINT8C;
typedef unsigned char __xdata UINT8X;
typedef unsigned char  __data             UINT8D;

#include <stdint.h>
#include <stdio.h>
#include <string.h>
#include "CH559.h"
#include "USBHost.h"
#include "util.h"
#include "console.h"
#include "retro_mouse.h"
#include "retro_joystick.h"
#include "config.h"
#include "hardware.h"
#include "led.h"

//CH559 Timer0 clock selection
//bTMR_CLK affects Timer0&1&2 at the same time, pay attention when using
#define mTimer0ClkFsys( ) (T2MOD |= bTMR_CLK | bT0_CLK) //timer, clock=Fsys
#define mTimer0Clk4DivFsys( ) (T2MOD &= ~bTMR_CLK;T2MOD |= bT0_CLK) //timer, clock=Fsys/4
#define mTimer0Clk12DivFsys( ) (T2MOD &= ~(bTMR_CLK | bT0_CLK)) //timer, clock= Fsys/12
#define mTimer0CountClk( ) (TMOD |= bT0_CT) //counter, the falling edge of T0 pin is valid


/* --------------------------------------------------
   Timer defines
-------------------------------------------------- */

#define BTN_STEP     10    // 1 second
#define BTN_T_BOOT   100   // 10 seconds

/* --------------------------------------------------
   Button variables
-------------------------------------------------- */

static uint8_t  btn_event = 0;

/* --------------------------------------------------
   Autofire
-------------------------------------------------- */

static uint16_t autofire_counter = 0;
static uint8_t autofire_state = 0;

static const uint16_t __code autofire_ticks[] =
{
    0,
    150,
    133,
    120,
    109,
    100
};

/* --------------------------------------------------
   Timer helpers
-------------------------------------------------- */

void mTimer0ModSetup(unsigned char mode)
{
    TMOD &= 0xf0;
    TMOD |= mode;
}

void mTimer0SetData(unsigned short dat)
{
    unsigned short tmp;
    tmp = 65536 - dat;
    TL0 = tmp & 0xff;
    TH0 = (tmp >> 8) & 0xff;
}

/* --------------------------------------------------
   TIMER ISR
-------------------------------------------------- */

/*
 * Called every 100 milliseconds from the ISR below.
 * Handles button presses and press durations
 */
void btn_tick()
{
    static uint16_t btn_ticks = 0;
    static uint8_t  btn_state = 0;
    static uint8_t level = 1;

    if(!(P4_IN & (1 << 6)))   // pressed (active low)
    {
        // initializes a new button press
        if(btn_state == 0)
        {
            btn_state = 1;
            btn_ticks = 0;
            level = 1;
        }

        btn_ticks++; // timer ticks

        // on fixed intervals
        if(btn_ticks % BTN_STEP == 0)
        {
            // next menu option
            if(level < 6)
            {
                level++;
                // puts("LED");
                led_activate(500, 500);
            } else
            // after 10 seconds activate firmware flash mode
            if(btn_ticks >= BTN_T_BOOT)
            {
                btn_ticks = BTN_T_BOOT;
                led_on();
                level = 7;
            }
        }
    }
    else // release
    {
        if(btn_state == 1)
        {
            btn_event = level; /* activates button event in main function */
            btn_state = 0;
            led_off();
        }
    }
}

/*
 * ISR of hardware timer 0. Called 2400 times per second!
 */
void mTimer0Interrupt(void) __interrupt INT_NO_TMR0
{
    static uint8_t ticks = 0;

    /* ---- MOUSE / JOYSTICK ---- */

    if(USBHost_getControllerMode() == CTRL_MODE_MOUSE)
    {
        rm_nextStep(); // generates mouse quadrature (movements)
    }
    else
    {
        /* joystick autofire button pressed ? */
        if(autofire_active)
        {
            autofire_counter++;

            if(autofire_counter >= autofire_ticks[g_config.joy_autofire_speed])
            {
                autofire_counter = 0;
                autofire_state ^= 1;
            }

            JOY_FIRE = autofire_state ? 0 : 1;
        }
    }

    /* ---- BUTTON HANDLING ---- */

    ticks++;

    /* prescaler 2400 hz / 240 = 10 hz or each 100 ms */
    if(ticks >= 240)
    {
        ticks = 0;

        if(console_get_state() == MENU_MAIN)
            btn_tick();

        led_tick();
    }

    mTimer0SetData(20000);  // reset timer 0 to 2400 Hz (48.000.000 / 20.000 = 2400 Hz)
}

/* --------------------------------------------------
   MAIN
-------------------------------------------------- */

/*
 * program start point
 */
void main()
{
    SP = 0x80;

    hw_setup();
    initClock();
    initUART0(1000000, 1);

    if(USBHost_getControllerMode() == CTRL_MODE_MOUSE)
        rm_init();
    else
        rj_init();

    if(!config_load())
    {
        puts("Config corrupt, defaults loaded");
        config_save();
    }

    resetHubDevices(0);
    initUSB_Host();

    console_start();

    mTimer0ModSetup(1);
    mTimer0ClkFsys();
    mTimer0SetData(20000 /*0x2323 */);

    TR0 = 1;
    ET0 = 1;
    EA  = 1;

    /* loop forever */
    while(1)
    {
        /* processes pcb button menu choices */
        if(btn_event)
        {
            uint8_t ev = btn_event;
            btn_event = 0;

            switch(ev)
            {
                case 1: show_main_menu(); break;
                case 2: start_learning(false); break;
                case 3: swap_mouse_mode(); break;
                case 4: swap_mouse_buttons(); break;
                case 5: inc_mouse_speed(); break;
                case 6: inc_autofire_speed(); break;
                case 7: runBootloader(); break;
            }
        }

        checkRootHubConnections(); // Detects and handles USB device connect/disconnect events on the root hub
        pollHIDdevice();           // Polls the active HID device for new input reports and processes them
        console_task();            // Handles console input/output, including command parsing and user interaction
    }
}

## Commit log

2026-03-17 hardware and readme
    [RetroLink.brd, RetroLink.sch, bom.xls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]
2026-04-08 led and pushbutton
2026-04-08 led connection
    [RetroLink.brd, RetroLink.sch]
2026-04-09 hardware changes
    [RetroLink.brd, RetroLink.sch, bom.xls]

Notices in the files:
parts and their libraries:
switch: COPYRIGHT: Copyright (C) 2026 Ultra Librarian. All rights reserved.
